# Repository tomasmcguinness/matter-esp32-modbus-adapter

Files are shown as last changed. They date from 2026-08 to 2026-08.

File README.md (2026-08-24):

# Matter ESP32 Modbus Adapter
The goal of this project is to provide a simple working Modbus adapter. It is designed for the ESP32-C6 MCU, so can be used with ESPHome, ESP-IDF and Arduino.

> [!WARNING]
> This is a work in progress. The code is working without issue, but the PCB (Revision A) has some design issues, which need addressing.

# Hardware

The hardware folder contains a KiCad PCB design, designed around the ESP32-C6-MINI-1. Both the antenna and non-antenna versions will work here.

# SDM120M - Electrical Sensor

The first device supported by this project is the Eastron SDM120M Single Phase Energy Meter

The readings from this device will be exposed using as a Matter Electrical Sensor Device Type.

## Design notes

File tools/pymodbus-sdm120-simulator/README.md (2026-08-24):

# pymodbus-sdm120-simulator

Simulates an Eastron SDM120M energy meter over Modbus RTU, so the adapter firmware
can be tested against a PC instead of (or alongside) the real meter or the
`tools/modbus-slave-simulator` hardware simulator.

Matches the registers `firmware/main/sdm120.cpp` reads (function code 0x04,
big-endian float32, no word swap):

| Register | Address | Value  |
|---|---|---|
| Voltage  | 0x0000  | 230.5 V|
| Current  | 0x0006  | 1.23 A |
| Power | 0x000C  | 283.2 W|
| Energy | 0x001A  | 12.34 kWh|

Edit the `float32` values in `config.json` to test different readings.

## Hardware

PC → YP-05 (USB↔TTL) → HW-519 (TTL↔RS485, auto direction) → A/B → adapter's RS485 bus.

The HW-519 handles TX/RX direction switching itself, so no RTS/DE toggling is needed
on the PC side.

Only one Modbus RTU slave can be on the bus at a time — unplug/power down the
`modbus-slave-simulator` board (or the real SDM120M) before starting this simulator.

## Setup

```
pip install pymodbus[serial] aiohttp
```

(Already satisfied if you've installed `pymodbus`, `pyserial`, and `aiohttp` for
other tools in this repo.)

Find the YP-05's COM port in Device Manager (it enumerates as a CH340 USB Serial
device — distinct from the ESP32 boards, which show up as `USB\VID_303A...`).
Edit `"port"` in `config.json` to match, e.g. `"COM5"`.

## Usage

Run from this directory:

```
pymodbus.simulator --modbus_server sdm120 --modbus_device sdm120 --json_file config.json
```

(`pymodbus.simulator` is the console script `pip` installs alongside the package —
run `where pymodbus.simulator` if it's not on your PATH.)

This starts the RTU server on the configured COM port, plus a web console at
`http://localhost:8080` where you can watch requests/responses live and edit
register values without restarting. You'll see two deprecation warnings
(`ModbusSimulatorContext`/`ModbusServerContext` "will be removed in v4") on
startup — harmless on the current 3.x releases, just pymodbus flagging that the
config format changes in 4.0.

Then run the adapter firmware (or point `tools/uart-send-byte`/a Modbus master
at the same bus) and it should read back the values above.

## Notes

- `"type exception": true` means any register the firmware queries that isn't
  defined in `config.json` returns a Modbus exception, same as a real meter
  would for an unsupported register.
- Registers are read-only (`"write": []`), matching the real SDM120M.

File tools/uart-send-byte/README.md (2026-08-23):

# uart-send-byte

Repeatedly sends a single byte over UART, once a second, using a YP-05 USB-to-serial adapter. Useful for quick hardware bring-up checks without flashing firmware. Stop with Ctrl+C.

## Setup

```
pip install pyserial
```

## Usage

### Sending

```
python send_byte.py --port COM5 --baud 9600 --byte 0x01
```

- `--port` (required) — serial port, e.g. `COM5` on Windows or `/dev/ttyUSB0` on Linux
- `--baud` (optional) — baud rate, default `9600`
- `--byte` (optional) — byte to send as decimal or hex (e.g. `0x01`), default `0x00`

### Receiving

```
python receive_byte.py --port COM5 --baud 9600
```

Listens on the given port and logs each byte received, with a timestamp, until stopped with Ctrl+C.

- `--port` (required) — serial port, e.g. `COM5` on Windows or `/dev/ttyUSB0` on Linux
- `--baud` (optional) — baud rate, default `9600`

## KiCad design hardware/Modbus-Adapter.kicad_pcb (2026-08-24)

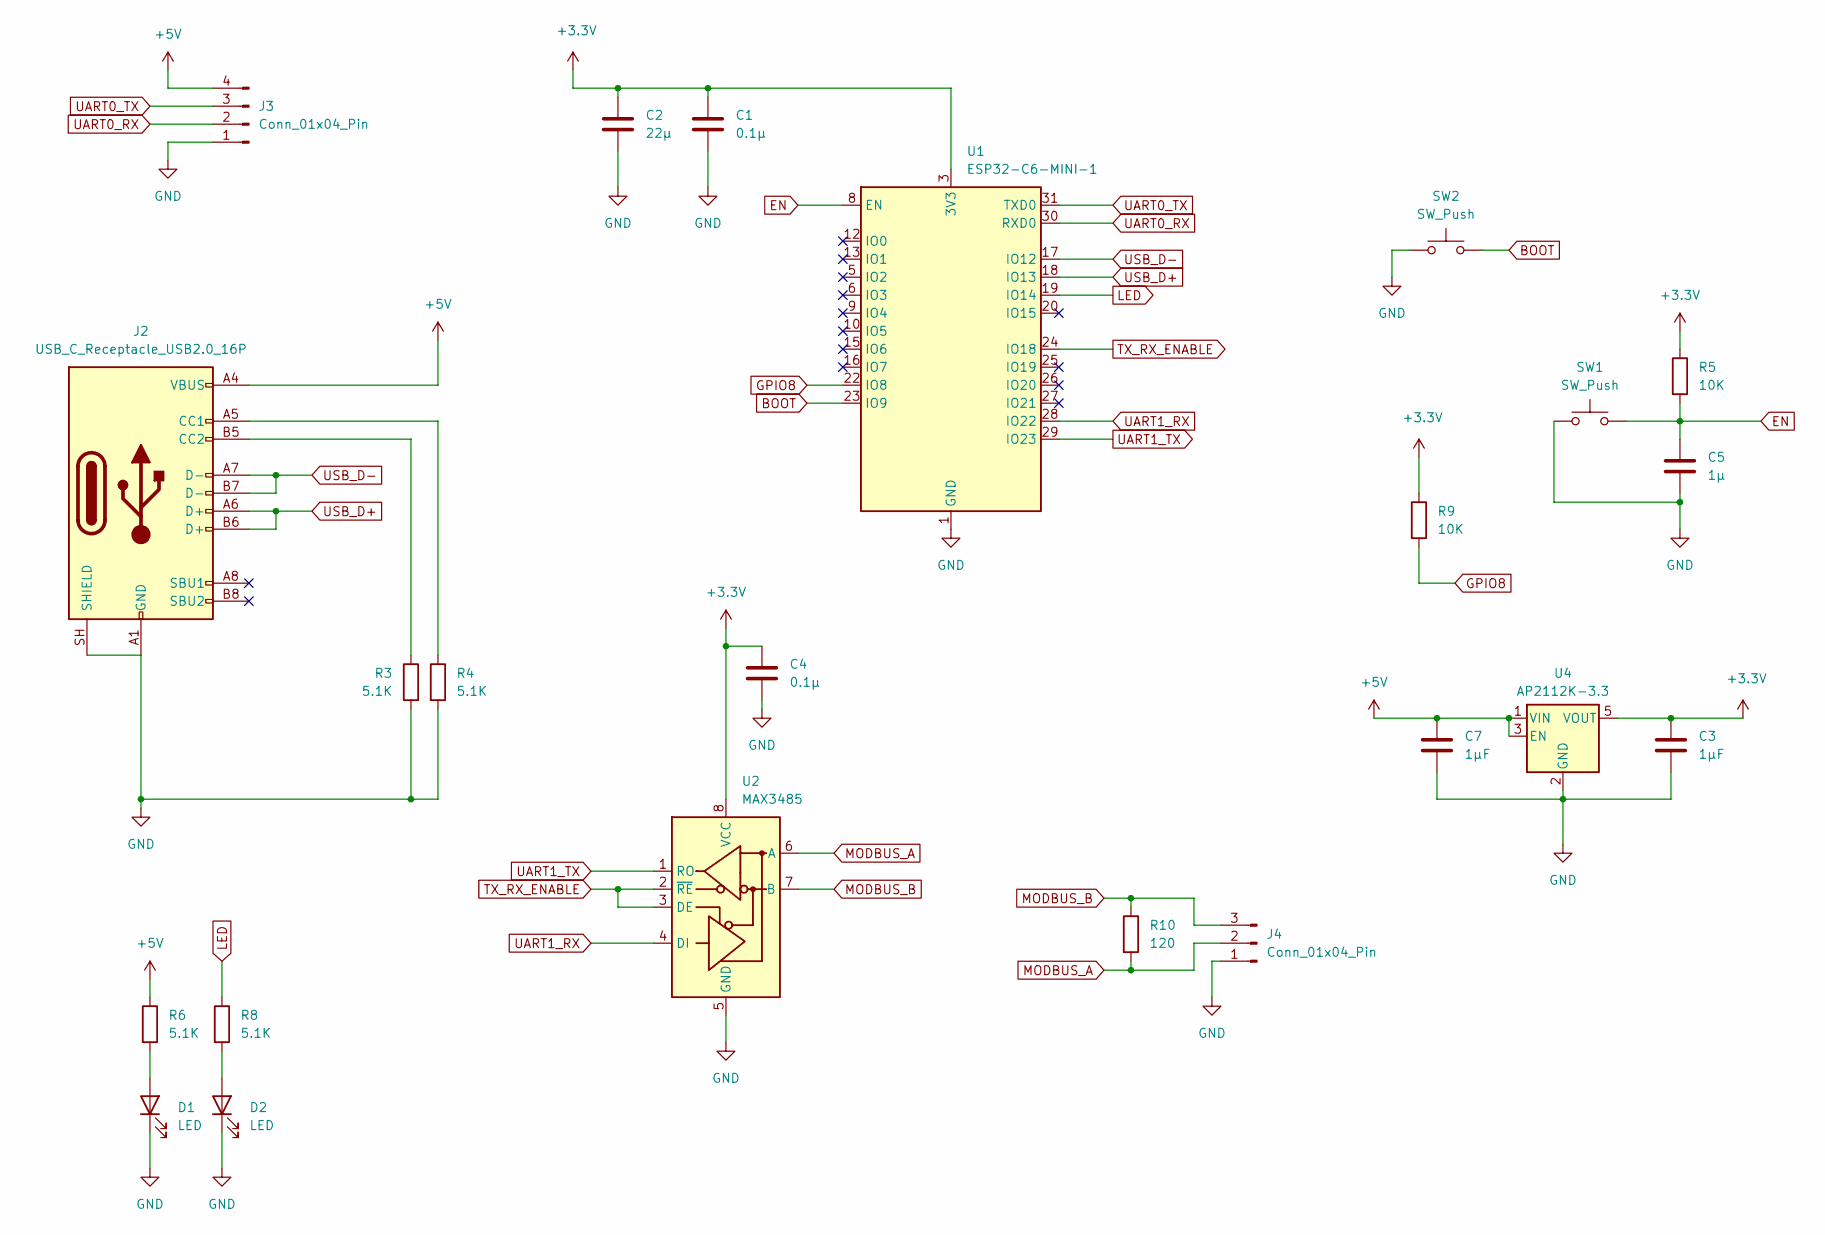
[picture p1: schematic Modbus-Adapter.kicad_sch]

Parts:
C1, C4: 0.1µ; C_0805_2012Metric
C2: 22µ; C_0805_2012Metric
C3, C7: 1µF; C_0805_2012Metric
C5: 1µ; C_0805_2012Metric
D1, D2: LED; LED_0805_2012Metric
J2: USB_C_Receptacle_USB2.0_16P; USB_C_Receptacle_GCT_USB4105-xx-A_16P_TopMnt_Horizontal
J3: Conn_01x04_Pin; PinHeader_1x04_P2.54mm_Vertical
J4: Conn_01x04_Pin; TerminalBlock_MaiXu_MX126-5.0-03P_1x03_P5.00mm
R3, R4, R6, R8: 5.1K; R_0805_2012Metric
R5, R9: 10K; R_0805_2012Metric
R10: 120; R_0805_2012Metric
SW1, SW2: SW_Push; SW_SPST_TS-1088-xR025
U1: ESP32-C6-MINI-1
U2: MAX3485; SOIC-8_3.9x4.9mm_P1.27mm
U4: AP2112K-3.3; SOT-23-5

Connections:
+3.3V: C1.1, C2.1, C3.1, C4.1, R5.1, R9.1, U1.3 (3V3), U2.8 (VCC), U4.5 (VOUT)
+5V: C7.1, J2.A4 (VBUS), J2.A9 (VBUS), J2.B4 (VBUS), J2.B9 (VBUS), J3.4, R6.1, U4.1 (VIN), U4.3 (EN)
BOOT: SW2.2, U1.23 (IO9)
EN: C5.1, R5.2, SW1.2, U1.8 (EN)
GND: C1.2, C2.2, C3.2, C4.2, C5.2, C7.2, D1.1 (K), D2.1 (K), J2.A1 (GND), J2.A12 (GND), J2.B1 (GND), J2.B12 (GND), J2.SH (SHIELD), J3.1, J4.1, R3.2, R4.2, SW1.1, SW2.1, U1.1 (GND), U1.2 (GND), U1.11 (GND), U1.14 (GND), U1.36 (GND), U1.37 (GND), U1.38 (GND), U1.39 (GND), U1.40 (GND), U1.41 (GND), U1.42 (GND), U1.43 (GND), U1.44 (GND), U1.45 (GND), U1.46 (GND), U1.47 (GND), U1.48 (GND), U1.49 (GND), U1.50 (GND), U1.51 (GND), U1.52 (GND), U1.53 (GND), U2.5 (GND), U4.2 (GND)
GPIO8: R9.2, U1.22 (IO8)
LED: R8.1, U1.19 (IO14)
MODBUS_A: J4.2, R10.2, U2.6 (A)
MODBUS_B: J4.3, R10.1, U2.7 (B)
unnamed: D1.2 (A), R6.2
unnamed: D2.2 (A), R8.2
unnamed: J2.A5 (CC1), R4.1
unnamed: J2.B5 (CC2), R3.1
TX_RX_ENABLE: U1.24 (IO18), U2.2 (~RE), U2.3 (DE)
UART0_RX: J3.2, U1.30 (RXD0)
UART0_TX: J3.3, U1.31 (TXD0)
UART1_RX: U1.28 (IO22), U2.4 (DI)
UART1_TX: U1.29 (IO23), U2.1 (RO)
USB_D+: J2.A6 (D+), J2.B6 (D+), U1.18 (IO13)
USB_D-: J2.A7 (D-), J2.B7 (D-), U1.17 (IO12)

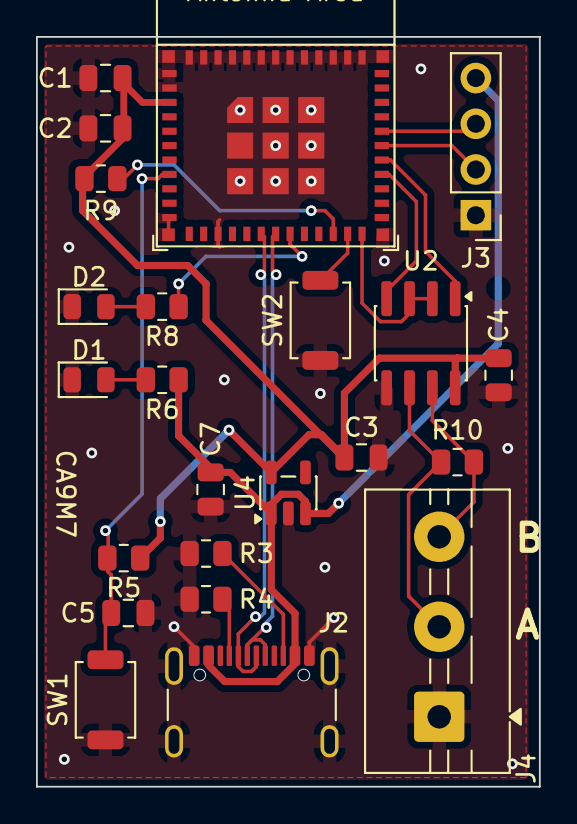
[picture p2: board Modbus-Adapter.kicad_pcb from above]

Board: 2 copper layers, 27.9 x 41.7 mm, 23 parts (0 on the bottom side), 20 nets.

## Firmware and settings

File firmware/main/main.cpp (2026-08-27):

#include <esp_err.h>
#include <esp_log.h>
#include <esp_matter.h>
#include <nvs_flash.h>

#include <app/server/CommissioningWindowManager.h>
#include <app/server/Server.h>
#include <setup_payload/OnboardingCodesUtil.h>
#include <setup_payload/QRCodeSetupPayloadGenerator.h>

#include "modbus.h"
#include "sdm120.h"
#include "status_led.h"

#include "freertos/FreeRTOS.h"
#include "freertos/task.h"

#if CONFIG_ENABLE_STATUS_DISPLAY
#include "status_display.h"
#endif
#include "electrical_power_measurement_delegate.h"

static chip::app::Clusters::ElectricalPowerMeasurement::ElectricalPowerMeasurementDelegate EPMDelegate;

static const char *TAG = "Main";

using namespace esp_matter;
using namespace esp_matter::attribute;
using namespace esp_matter::cluster;
using namespace esp_matter::endpoint;

using namespace chip::app::Clusters;

static uint16_t electrical_sensor_endpoint_id = 0;

// RS-485 bring-up tests. 0 = off (normal SDM120M polling), 1 = transmit one
// byte repeatedly, 2 = receive and log bytes, 3 = transmit a byte and listen
// for it (jumper TXD to RXD to bypass the transceiver).
#define MODBUS_LINK_TEST 0

#define ABORT_APP_ON_FAILURE(x, ...)               \
    do                                             \
    {                                              \
        if (!(unlikely(x)))                        \
        {                                          \
            __VA_ARGS__;                           \
            vTaskDelay(5000 / portTICK_PERIOD_MS); \
            abort();                               \
        }                                          \
    } while (0)

static bool is_commissioned()
{
    return chip::Server::GetInstance().GetFabricTable().FabricCount() > 0;
}

static void open_commissioning_window_if_necessary()
{
    VerifyOrReturn(chip::Server::GetInstance().GetFabricTable().FabricCount() == 0);

    chip::CommissioningWindowManager &mgr = chip::Server::GetInstance().GetCommissioningWindowManager();
    VerifyOrReturn(mgr.IsCommissioningWindowOpen() == false);

    CHIP_ERROR err = mgr.OpenBasicCommissioningWindow(
        chip::System::Clock::Seconds16(300),
        chip::CommissioningWindowAdvertisement::kDnssdOnly);

    if (err != CHIP_NO_ERROR)
    {
        ESP_LOGE(TAG, "Failed to open commissioning window: %" CHIP_ERROR_FORMAT, err.Format());
    }
}

static void app_event_cb(const ChipDeviceEvent *event, intptr_t arg)
{
    switch (event->Type)
    {
    case chip::DeviceLayer::DeviceEventType::kCommissioningComplete:
        ESP_LOGI(TAG, "Commissioning complete");
        status_led_set_state(STATUS_LED_OPERATIONAL);
        break;
    case chip::DeviceLayer::DeviceEventType::kCommissioningSessionStarted:
        ESP_LOGI(TAG, "Commissioning session started");
        status_led_set_state(STATUS_LED_PAIRING);
        break;
    case chip::DeviceLayer::DeviceEventType::kCommissioningSessionStopped:
        // Also fires when a pairing attempt is abandoned or fails, in which
        // case the window is still open and the device is pairable again.
        ESP_LOGI(TAG, "Commissioning session stopped");
        status_led_set_state(is_commissioned() ? STATUS_LED_OPERATIONAL : STATUS_LED_READY_TO_PAIR);
        break;
    case chip::DeviceLayer::DeviceEventType::kCommissioningWindowClosed:
        ESP_LOGI(TAG, "Commissioning window closed");
        status_led_set_state(is_commissioned() ? STATUS_LED_OPERATIONAL : STATUS_LED_OFF);
#if CONFIG_ENABLE_STATUS_DISPLAY
        StatusDisplayMgr().ClearCommissioningCode();
#endif
        break;
    case chip::DeviceLayer::DeviceEventType::kCommissioningWindowOpened:
    {
        ESP_LOGI(TAG, "Commissioning window opened");

        status_led_set_state(STATUS_LED_READY_TO_PAIR);

        chip::RendezvousInformationFlags rendezvousFlags = chip::RendezvousInformationFlags(chip::RendezvousInformationFlag::kBLE);

        chip::PayloadContents payload;
        GetPayloadContents(payload, rendezvousFlags);

        char payloadBuffer[chip::QRCodeBasicSetupPayloadGenerator::kMaxQRCodeBase38RepresentationLength + 1];
        chip::MutableCharSpan qrCode(payloadBuffer);

        if (GetQRCode(qrCode, payload) == CHIP_NO_ERROR)
        {
            ESP_LOGI(TAG, "Generated QR CODE [%d]: %s", qrCode.size(), qrCode.data());
#if CONFIG_ENABLE_STATUS_DISPLAY
            StatusDisplayMgr().SetCommissioningCode(qrCode.data(), qrCode.size());
#endif
        }
        else
        {
            ESP_LOGE(TAG, "Failed to generate the commissioning QR code");
        }
        break;
    }
    case chip::DeviceLayer::DeviceEventType::kFabricRemoved:
        ESP_LOGI(TAG, "Fabric removed");
        open_commissioning_window_if_necessary();
        break;
    case chip::DeviceLayer::DeviceEventType::kBLEDeinitialized:
        ESP_LOGI(TAG, "BLE deinitialized");
        break;
    default:
        break;
    }
}

static esp_err_t app_identification_cb(identification::callback_type_t type, uint16_t endpoint_id,
                                       uint8_t effect_id, uint8_t effect_variant, void *priv_data)
{
    return ESP_OK;
}

extern "C" void matter_update_voltage(float voltage_v)
{
    chip::DeviceLayer::SystemLayer().ScheduleLambda([voltage_v] {
        EPMDelegate.SetVoltage(chip::app::DataModel::MakeNullable((int64_t)(voltage_v * 1000.0f))); // V → mV
    });
}

extern "C" void matter_update_current(float current_a)
{
    chip::DeviceLayer::SystemLayer().ScheduleLambda([current_a] {
        EPMDelegate.SetActiveCurrent(chip::app::DataModel::MakeNullable((int64_t)(current_a * 1000.0f))); // A → mA
    });
}

extern "C" void matter_update_power(float power_w)
{
    chip::DeviceLayer::SystemLayer().ScheduleLambda([power_w] {
        EPMDelegate.SetActivePower(chip::app::DataModel::MakeNullable((int64_t)(power_w * 1000.0f))); // W → mW
    });
}

static esp_err_t app_attribute_update_cb(attribute::callback_type_t type, 
                                         uint16_t endpoint_id,
                                         uint32_t cluster_id, 
                                         uint32_t attribute_id,
                                         esp_matter_attr_val_t *val, 
                                         void *priv_data)
{
    return ESP_OK;
}

extern "C" void app_main()
{
    nvs_flash_init();

    status_led_init();

#if CONFIG_ENABLE_STATUS_DISPLAY
    StatusDisplayMgr().Init();
    StatusDisplayMgr().TurnOn();
    ESP_LOGI(TAG, "Display initialized");
#endif

    modbus_uart_init();
    ESP_LOGI(TAG, "Modbus UART initialized");

    // Create the root endpoint
    node::config_t node_config;
    node_t *node = node::create(&node_config, app_attribute_update_cb, app_identification_cb);
    ABORT_APP_ON_FAILURE(node != nullptr, ESP_LOGE(TAG, "Failed to create Matter node"));

    electrical_sensor::config_t electrical_sensor_config;
    // Configure the sensor as a node.
    electrical_sensor_config.power_topology.feature_flags = power_topology::feature::node_topology::get_id();

    // Configure AC as the power type.
    electrical_sensor_config.electrical_power_measurement.feature_flags = electrical_power_measurement::feature::alternating_current::get_id();
    electrical_sensor_config.electrical_power_measurement.delegate = &EPMDelegate;

    endpoint_t *endpoint = electrical_sensor::create(node, &electrical_sensor_config, ENDPOINT_FLAG_NONE, NULL);
    ABORT_APP_ON_FAILURE(endpoint != nullptr, ESP_LOGE(TAG, "Failed to create electrical sensor endpoint"));
    electrical_sensor_endpoint_id = endpoint::get_id(endpoint);

    cluster_t *cluster = cluster::get(endpoint, chip::app::Clusters::ElectricalPowerMeasurement::Id);
    ABORT_APP_ON_FAILURE(cluster != nullptr, ESP_LOGE(TAG, "Failed to get EPM cluster from endpoint"));

    electrical_power_measurement::attribute::create_voltage(cluster, 0);
    electrical_power_measurement::attribute::create_active_current(cluster, 0);
    electrical_power_measurement::attribute::create_active_power(cluster, 0);

    esp_err_t err = esp_matter::start(app_event_cb);
    if (err != ESP_OK)
    {
        ESP_LOGE(TAG, "Failed to start Matter: %d", err);
        return;
    }

#if MODBUS_LINK_TEST == 1
    modbus_start_tx_test();
#elif MODBUS_LINK_TEST == 2
    modbus_start_rx_test();
#elif MODBUS_LINK_TEST == 3
    modbus_start_loopback_test();
#else
    xTaskCreate(sdm120_read_task, "sdm120m_read", 4096, NULL, 5, NULL);
#endif
}

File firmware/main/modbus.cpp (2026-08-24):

#include "modbus.h"
#include "driver/uart.h"
#include "driver/gpio.h"
#include "freertos/FreeRTOS.h"
#include "freertos/task.h"
#include "freertos/queue.h"
#include "esp_log.h"
#include <string.h>

// Revision A Board. TX GPIO22, RX GPIO23, DE/RE GPIO18. 9600 baud, 8N1, no flow control.

#define MODBUS_UART     UART_NUM_1
#define TXD_PIN         ((gpio_num_t)22)
#define RXD_PIN         ((gpio_num_t)23)
#define DE_RE_PIN       ((gpio_num_t)18)
#define MODBUS_SLAVE_ADDR 1

#define RX_TEST_TIMEOUT_MS 2000
#define LOOPBACK_TIMEOUT_MS 200

// ESP-IDF's printf has no %b, so expand the byte into eight explicit bits.
#define BYTE_TO_BINARY_FMT "%c%c%c%c%c%c%c%c"
#define BYTE_TO_BINARY(b)                               \
    ((b) & 0x80 ? '1' : '0'), ((b) & 0x40 ? '1' : '0'), \
    ((b) & 0x20 ? '1' : '0'), ((b) & 0x10 ? '1' : '0'), \
    ((b) & 0x08 ? '1' : '0'), ((b) & 0x04 ? '1' : '0'), \
    ((b) & 0x02 ? '1' : '0'), ((b) & 0x01 ? '1' : '0')

static const char *TAG = "Modbus";

static const uint16_t crc_table[] = {
    0x0000, 0xCC01, 0xD801, 0x1400, 0xF001, 0x3C00, 0x2800, 0xE401,
    0xA001, 0x6C00, 0x7800, 0xB401, 0x5000, 0x9C01, 0x8801, 0x4400};

static uint16_t crc16_modbus(uint8_t *data, int len)
{
    uint16_t crc = 0xFFFF;
    for (int i = 0; i < len; i++)
    {
        uint16_t tbl_idx = (crc ^ data[i]) & 0x0F;
        crc = (crc >> 4) ^ crc_table[tbl_idx];
        tbl_idx = (crc ^ (data[i] >> 4)) & 0x0F;
        crc = (crc >> 4) ^ crc_table[tbl_idx];
    }
    return crc;
}

static float bytes_to_float(const uint8_t *bytes)
{
    // Cast each byte before shifting: uint8_t promotes to int, so bytes[0] << 24
    // shifts into the sign bit for any value >= 0x80.
    uint32_t val = ((uint32_t)bytes[0] << 24) | ((uint32_t)bytes[1] << 16) |
                   ((uint32_t)bytes[2] << 8) | (uint32_t)bytes[3];

    // memcpy rather than a pointer cast; type-punning through *(float *)&val
    // breaks strict aliasing and the optimiser is free to reorder around it.
    float result;
    memcpy(&result, &val, sizeof(result));
    return result;
}

// Configures the UART and DE/RE pin. Pass a queue handle to receive driver
// events (framing errors, breaks); pass NULL for plain byte-oriented use.
static void modbus_uart_configure(QueueHandle_t *event_queue)
{
    uart_config_t uart_config = {
        .baud_rate = 9600,
        .data_bits = UART_DATA_8_BITS,
        .parity = UART_PARITY_DISABLE,
        .stop_bits = UART_STOP_BITS_1,
        .flow_ctrl = UART_HW_FLOWCTRL_DISABLE,
    };

    uart_param_config(MODBUS_UART, &uart_config);
    uart_set_pin(MODBUS_UART, TXD_PIN, RXD_PIN, UART_PIN_NO_CHANGE, UART_PIN_NO_CHANGE);
    uart_driver_install(MODBUS_UART, 256, 0, event_queue ? 20 : 0, event_queue, 0);

    gpio_config_t io_conf = {
        .pin_bit_mask = (1ULL << DE_RE_PIN),
        .mode = GPIO_MODE_OUTPUT,
        .pull_up_en = GPIO_PULLUP_DISABLE,
        .pull_down_en = GPIO_PULLDOWN_DISABLE,
        .intr_type = GPIO_INTR_DISABLE,
    };
    gpio_config(&io_conf);
    gpio_set_level(DE_RE_PIN, 0); // Start in RX mode
}

void modbus_uart_init(void)
{
    modbus_uart_configure(NULL);
}

static void modbus_tx_test_task(void *arg)
{
    gpio_set_level(DE_RE_PIN, 1); // hold driver enabled for the whole test
    vTaskDelay(pdMS_TO_TICKS(2));

    uint8_t byte = 0x48; // change freely - pick something easy to spot on a scope/logic analyzer
    while (1)
    {
        uart_write_bytes(MODBUS_UART, &byte, 1);
        uart_wait_tx_done(MODBUS_UART, pdMS_TO_TICKS(100));
        ESP_LOGI(TAG, "TX 0x%02X (0b" BYTE_TO_BINARY_FMT ")", byte, BYTE_TO_BINARY(byte));
        vTaskDelay(pdMS_TO_TICKS(1000));
    }
}

void modbus_start_tx_test(void)
{
    xTaskCreate(modbus_tx_test_task, "modbus_tx_test", 2048, NULL, 5, NULL);
}

static void modbus_rx_test_task(void *arg)
{
    // Reinstall the driver with an event queue. uart_read_bytes silently drops
    // framing errors, so a dead line and a garbled line look identical through
    // it; the event queue tells them apart.
    QueueHandle_t events = NULL;
    uart_driver_delete(MODBUS_UART);
    modbus_uart_configure(&events);

    gpio_set_level(DE_RE_PIN, 0); // hold the receiver enabled for the whole test
    vTaskDelay(pdMS_TO_TICKS(2));
    uart_flush_input(MODBUS_UART);

    ESP_LOGI(TAG, "RX test started, listening on UART%d", MODBUS_UART);

    while (1)
    {
        uart_event_t event;
        if (!xQueueReceive(events, &event, pdMS_TO_TICKS(RX_TEST_TIMEOUT_MS)))
        {
            ESP_LOGW(TAG, "RX idle (no bytes in %d ms)", RX_TEST_TIMEOUT_MS);
            continue;
        }

        switch (event.type)
        {
        case UART_DATA:
            for (size_t i = 0; i < event.size; i++)
            {
                uint8_t byte = 0;
                if (uart_read_bytes(MODBUS_UART, &byte, 1, 0) == 1)
                {
                    ESP_LOGI(TAG, "RX 0x%02X (0b" BYTE_TO_BINARY_FMT ")", byte, BYTE_TO_BINARY(byte));
                }
            }
            break;

        case UART_FRAME_ERR:
        {
            ESP_LOGE(TAG, "RX FRAMING ERROR - signal is arriving but the stop bit is wrong.");
            // Log whatever the driver kept, if anything. If the data bits are
            // correct and only the stop bit failed, the sender is releasing the
            // bus before the frame completes (auto-direction turnaround).
            uint8_t byte = 0;
            while (uart_read_bytes(MODBUS_UART, &byte, 1, 0) == 1)
            {
                ESP_LOGE(TAG, "  bad frame carried 0x%02X (0b" BYTE_TO_BINARY_FMT ")",
                         byte, BYTE_TO_BINARY(byte));
            }
            break;
        }

        case UART_BREAK:
            ESP_LOGE(TAG, "RX BREAK - line held low for a full frame.");
            ESP_LOGE(TAG, "  Nobody is driving the bus. A terminated pair with no failsafe");
            ESP_LOGE(TAG, "  bias sits at 0V differential, which the MAX485 cannot resolve.");
            break;

        case UART_PARITY_ERR:
            ESP_LOGE(TAG, "RX PARITY ERROR - sender is not 8N1.");
            break;

        case UART_FIFO_OVF:
        case UART_BUFFER_FULL:
            ESP_LOGW(TAG, "RX overflow - data arriving faster than it is drained.");
            uart_flush_input(MODBUS_UART);
            break;

        default:
            ESP_LOGW(TAG, "RX event type %d", (int)event.type);
            break;
        }
    }
}

void modbus_start_rx_test(void)
{
    xTaskCreate(modbus_rx_test_task, "modbus_rx_test", 2048, NULL, 5, NULL);
}
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

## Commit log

2026-08-03 Renamed the files. Finished the first pass
    [Modbus-Adapter.kicad_pcb, Modbus-Adapter.kicad_sch, PCB.kicad_pcb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]
2026-08-14 Enhance README with project details and warnings
    Expanded project description to include compatibility with ESPHome, ESP-IDF, and Arduino. Added a warning about PCB design issues.
2026-08-23 Add simple python toosl to send and receive single bytes over UART
2026-08-23 Fix pins for board. Add test routine to send and receive single bytes.
    [main.cpp, modbus.cpp]
2026-08-23 Ignore lock files for kicad
2026-08-24 Revision B of the PCB
    [Modbus-Adapter.kicad_pcb]
2026-08-24 Small changes to modbus frame handling (claude)
2026-08-27 Implement status LED for pairing
2026-08-30 Fix layout
    [PCB.kicad_pcb, PCB.kicad_sch]
